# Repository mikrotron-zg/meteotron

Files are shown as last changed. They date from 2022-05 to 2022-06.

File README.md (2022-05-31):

# Meteotron

A simple weather station project based on [Adafruit](https://www.adafruit.com/) Feather ESP32-S2 and BME680. Basic version reads temperature, relative humidity and atmospheric pressure, connects to local Wi-Fi and sends data to [ThingsBoard](https://demo.thingsboard.io/) demo server. You can find current data from our test setup [here](https://bit.ly/3z5tDIx).

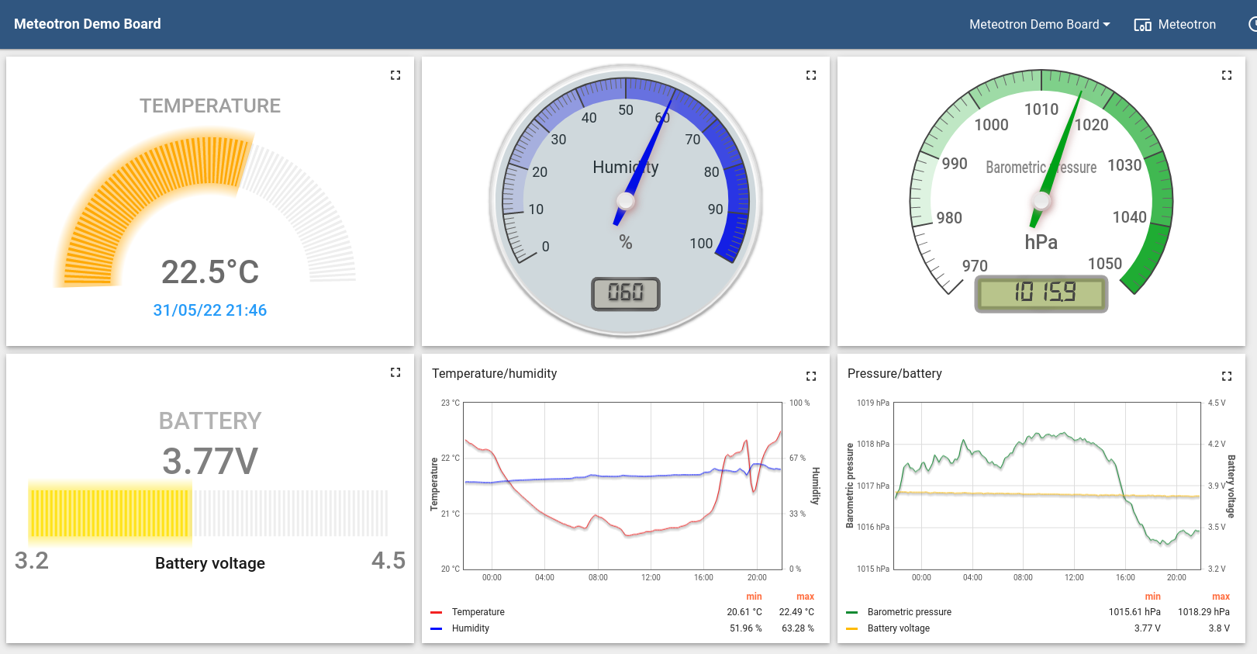
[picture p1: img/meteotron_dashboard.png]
meteotron dashboard


## Hardware

Hardware needed for this project:
* [Adafruit ESP32-S2 Feather](https://www.diykits.eu/products/wireless/p_12015) - great microcontroller board by [Adafruit](https://www.adafruit.com/), with some nice sleep/low power functions we're gonna need
* [BME680 Sensor Breakout](https://www.diykits.eu/products/sensors/p_11997) - reads temperature, relative humidity, atmospheric pressure and VOC (we won't be using this, so will probably switch to some other sensor once the chip shortage is over)
* [easyC cable - 10 cm](https://www.diykits.eu/products/connectorsandwires/p_11733) - eascyC or Stemma QT or Qwiic, it's all the same, easy way to connect I2C (IIC) devices
* [Li-ion battery 2100mAh 3.7V](https://www.diykits.eu/products/power/p_12004) - should be enough for what we need

Also, we can go solar by using:
* [Mini Solar Panel 5V 500mA](https://www.diykits.eu/products/power/p_10668) and
* [CN3065 Solar Lithium Charger Board](https://www.diykits.eu/products/power/p_11930) 

## Software

Project software is written in [VS Code](https://code.visualstudio.com/) with [PlatformIO](https://platformio.org/) plugin, but it can be compiled using [Arduino IDE](https://www.arduino.cc/en/software) (you might need to change a few things here and there, and manually download the libraries used in the project, but it should work). 

Before compiling, you must add your credentials (WiFi, ThingsBoard, etc), so please follow the instructions in _include/CredentialsTemplate.h_ file.

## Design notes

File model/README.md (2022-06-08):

3D model source files, you'll need [OpenSCAD](https://openscad.org/) to render and export STL files for 3D print.

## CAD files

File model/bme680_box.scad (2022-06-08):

/* Box for BME680 sensor module by e-radionica
 * by Mikrotron d.o.o. 2022
 * see the project root for license
 */

// should be in the same directory
include <mini_solar_common.scad>

// geometry
bme_length = 27.5;
bme_width = 16.5;
bme_pcb_height = 1.6;
bme_mthole_dia = 3.2;
bme_mthole_offset = 2.9;
wall_offset = 7;
box_wall = 2.4;
box_length = bme_length + 4*wall_offset;
box_width = bme_width + 2*wall_offset;
box_height = 16;
box_mh_offset = 4;
corner_radius = wall_offset + 2.8;
mh = mount_holes();
standoff_h = 3;

// entry point
bme680_box();

module bme680_box() {
    bme680_box_bottom();
    // translate([-box_wall, -box_wall, 0]) #bme680_box_top(); // used for construction
    translate([0, 2.25*box_width, box_height]) rotate([180, 0, 0]) bme680_box_top();
}

module bme680_box_top() {
    // top part of the box
    top_length = box_length + 2*box_wall;
    top_width = box_width + 2*box_wall;
    corner_height = box_height - 2*box_wall - standoff_h - 2*bme_pcb_height;
    difference() {
        union() {
            difference() {
                // body
                cube([top_length, top_width, box_height]);
                translate([box_wall, box_wall, -ex]) 
                    cube([box_length, box_width, box_height - box_wall + ex]);
                // vent grid
                translate([top_length/4, top_width/4, box_height - box_wall - ex]) {
                    for (i = [0 : top_length/20 : top_length/2]) {
                        translate([i, 0, 0]) cube([0.75, top_width/2, box_wall + 2*ex]);
                    }
                }
                // wire inlet
                translate([top_length - box_wall - ex, top_width/2 - inlet_width/2, box_wall]) 
                    cube([box_wall + 2*ex, inlet_width, inlet_height]);
            }
            // corners
            translate([box_wall, box_wall, box_height - box_wall - corner_height]) 
                cylinder_quarter(corner_radius, corner_height);
            translate([top_length - box_wall, top_width - box_wall, box_height - box_wall - corner_height]) 
                rotate(180) cylinder_quarter(corner_radius, corner_height);
        }
        // corner screw holes
        translate([box_wall + box_mh_offset, box_wall + box_mh_offset, box_height + ex]) 
            rotate([0, 180, 0]) m3_flathead_screw();
        translate([top_length - box_wall - box_mh_offset, top_width -box_wall - box_mh_offset, box_height + ex]) 
            rotate([0, 180, 0]) m3_flathead_screw();
    }
}

module bme680_box_bottom() {
    // bottom part of the box
    translate([wall_offset, wall_offset, box_wall + standoff_h]) %bme680();
    difference() {
        // body
        union() {
            cube([box_length, box_width, box_wall]);
            translate([0, 0, box_wall]) cylinder_quarter(corner_radius, standoff_h + 2*bme_pcb_height);
            translate([box_length, box_width, box_wall]) 
                rotate(180) cylinder_quarter(corner_radius, standoff_h + 2*bme_pcb_height);
            standoffs();
        }
        // holes for M2.5 screws
        translate([wall_offset, wall_offset, -ex]) {
            translate(mh[1]) cylinder(d = m25_dia, h = box_wall + standoff_h + 2*ex);
            translate(mh[3]) cylinder(d = m25_dia, h = box_wall + standoff_h + 2*ex);
        }
        // bottom nut traps
        translate([box_mh_offset, box_mh_offset, -ex]) nut_trap();
        translate([box_length - box_mh_offset, box_width - box_mh_offset, -ex]) nut_trap();
    }
}

module nut_trap() {
    // M3 nut trap
    cylinder(r = m3_nut_radius, h = 6, $fn = 6); 
    cylinder(d = m3_dia, h = box_wall + standoff_h + 2*bme_pcb_height + 2*ex);
}

module standoffs() {
    // BME680 standoffs
    translate([wall_offset, wall_offset, box_wall]) {
        for(mh = mount_holes()) translate(mh) cylinder(d1 = 8, d2 = 6, h = standoff_h);
        translate([0, 0, standoff_h]) {
            translate(mh[0]) cylinder(d = 2.75, h = 2*bme_pcb_height);
            translate(mh[2]) cylinder(d = 2.75, h = 2*bme_pcb_height);
        }
    }
}

//*************************** BME680 sensor module mockup *******************************

module bme680() {
    difference() {
        cube([bme_length, bme_width, bme_pcb_height]);
        for(mh = mount_holes()) translate(mh) bme_mthole();
    }
    translate([0, bme_width/2, bme_pcb_height]) rotate(-90) bme_connector();
    translate([bme_length, bme_width/2, bme_pcb_height]) rotate(90) bme_connector();
}

module bme_connector() {
    translate([-2.5, 0, 0]) cube([5, 4, 3.1]);
}

module bme_mthole() {
    cylinder(d = bme_mthole_dia, h = bme_pcb_height + 2*ex);
}

function mount_holes() =  [[bme_mthole_offset, bme_mthole_offset, -ex], 
                        [bme_length - bme_mthole_offset, bme_mthole_offset, -ex], 
                        [bme_length - bme_mthole_offset, bme_width - bme_mthole_offset, -ex], 
                        [bme_mthole_offset, bme_width - bme_mthole_offset, -ex]];

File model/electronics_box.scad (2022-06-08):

/* Electronics box (except for BME sensor,
 * we need it outside)
 * by Mikrotron d.o.o. 2022
 * see the project root for license
 */

// should be in the same directory
include <mini_solar_common.scad>;

// geometry
pcb_height = 1.6;
component_offset = 7.5;

// battery dimensions
bat_length = 62;
bat_width = 38;
bat_height = 9;

// charger dimensions
chrg_length = 40.5;
chrg_width = 20.5;
chrg_height = 8;

// feather dimensions
fthr_length = 50.8;
fthr_width = 23.0;
fthr_height = 7.2;
fthr_mnt_hole_dia = 2.54;
fthr_standoff_height = 5;

// box dimensions
box_length = bat_length + fthr_width + 3*component_offset;
box_width = chrg_width + bat_width + 3*component_offset;
box_height = fthr_height + 2*fthr_standoff_height + 5;
box_wall = 2.4;
bracket_distance = 95; // center to center!
corner_screw_offset = 6;

// entry point
mini_solar_box();

module mini_solar_box() {
    // comment out part if not needed
    color("Orange") box_top();
    translate([0, box_width*1.25, 0]) box_bottom();
}

module box_top() {
    // top part of the box
    difference() {
        translate([box_wall/2, box_wall/2, 0]) {
            rounded_rect(box_length - box_wall, box_width - box_wall, box_wall, box_wall/2);
        }
        // add corner screw holes
        translate([0, 0, box_wall + ex]) corner_screw_holes();
    }
    // add brackets
    translate([box_length/2 - bracket_distance/2, box_width/2, box_wall]) bracket();
    translate([box_length/2 + bracket_distance/2, box_width/2, box_wall]) bracket();
}

module corner_screw_holes(screw = true) {
    off = corner_screw_offset;
    translate([off, off, -ex]) m3_screw(screw);
    translate([box_length - off, off, -ex]) m3_screw(screw);
    translate([box_length - off, box_width - off, -ex]) m3_screw(screw);
    translate([off, box_width - off, -ex]) m3_screw(screw);
}

module corner() {
    radius = corner_screw_offset + 2.5;
    height = box_height - 2*box_wall;
    insert_height = height - 5;
    difference() {
        cylinder_quarter(r = radius, h = height);
        translate([corner_screw_offset - box_wall, corner_screw_offset - box_wall, insert_height]) 
            rotate(45) m3_screw(false);
        translate([radius/2 + 0.5, radius/2 + 0.5, insert_height]) 
            rotate(45) m3_screw(false);
    }
}

module corners() {
    translate([box_wall, box_wall, box_wall])  corner();
    translate([box_wall, box_width - box_wall, box_wall]) rotate(-90) corner();
    translate([box_length - box_wall, box_width - box_wall, box_wall]) rotate(180) corner();
    translate([box_length - box_wall, box_wall, box_wall]) rotate(90) corner();
}

module box_bottom() {
    // bottom part of the box
    difference() {
        rounded_rect(box_length, box_width, box_height, box_wall);
        translate([box_wall/2, box_wall/2, box_height - box_wall])
            rounded_rect(box_length - box_wall, box_width - box_wall, box_wall + 2*ex, box_wall/2);
        translate([box_wall, box_wall, box_wall])
            rounded_rect(box_length - 2*box_wall, box_width - 2*box_wall, box_height - box_wall, box_wall/2);
        // add power inlet
        translate([0.6*box_length, -ex, box_height/2])
            cube([inlet_width, box_wall + 2*ex, inlet_height]);
        // add-on mounts
        translate([bat_length + 2*component_offset, 4*component_offset, -ex]) bme680_mount(true);
    }
    // add corner screw mounts
    difference() {
        corners();
        translate([0, 0, box_height]) corner_screw_holes();
    }
    // components placement
    translate([0,0, box_wall]) {
        translate([component_offset + 1, chrg_width + 2*component_offset - 1, 0]) {
            battery_mount();
            %battery();    
        }
        translate([component_offset + bat_length/2 - chrg_length/2, component_offset, 0]) {
            translate([-box_wall/2, -box_wall/2, 0]) 
                charger_mount(chrg_length, chrg_width, 3);
            translate([0, 0, pcb_height]) %charger();
        }
        translate([bat_length + fthr_width + 2*component_offset, 2*component_offset, 0]) 
            rotate(90) {
                fthr_mount();
                translate([0, 0, fthr_standoff_height]) %feather();
            }
    }
    // add-on mounts
    translate([bat_length + 2*component_offset, 4*component_offset, box_wall]) bme680_mount();
}

//********************************* Component mounts *********************************************

module charger_mount(length, width, height) {
    // solar charger mount
    difference() {
        cube([length + box_wall, width + box_wall, height]);
        translate([box_wall/2, box_wall/2, height - pcb_height])
            cube([length, width, height + 2*ex]);
        translate([box_wall, box_wall, -ex])
            cube([length - box_wall, width - box_wall, height]);
        translate([-ex, width/2 - box_wall, 0])
            cube([length + 2*box_wall + 2*ex, 2*box_wall, height + ex]);
    }
    // hooks
    translate([length/4, 0, height]) hook();
    translate([3*length/4, 0, height]) hook();
    translate([length/4, width + box_wall, height]) rotate(180) hook();
    translate([3*length/4, width + box_wall, height]) rotate(180) hook();
}

module hook() {
    translate([-1, 0, 0]) cube([2, box_wall/2 + 0.4, box_wall/2]);
}

module fthr_mount() {
    // Adafruit Feather board mount
    translate([fthr_mnt_hole_dia, fthr_mnt_hole_dia, 0]) fthr_standoff();
    translate([fthr_mnt_hole_dia, fthr_width - fthr_mnt_hole_dia, 0]) fthr_standoff();
    ledge = 5;
    translate([fthr_length - ledge, -box_wall, 0]) difference() {
        cube([ledge + box_wall , fthr_width + 2*box_wall, fthr_standoff_height + 2*pcb_height]);
        translate([0, box_wall, fthr_standoff_height])
            cube([ledge, fthr_width, 1.5*pcb_height]);
        translate([0, box_wall + 1, fthr_standoff_height + 1.5*pcb_height])
            cube([ledge, fthr_width - 2, pcb_height]);
    }
}

module fthr_standoff() {
    difference() {
        screw_dia = m25_dia - 0.25; // m25_dia is for holes, we need this to be tight!
        cylinder(d1 = fthr_mnt_hole_dia + 6, d2 = fthr_mnt_hole_dia + 2, h = fthr_standoff_height);
        cylinder(d = screw_dia, h = fthr_standoff_height + ex);
    }
}

module battery_mount() {
    // lipo battery mount
    translate([bat_length/2, 0, 0]) rotate(90) battery_mount_clip(bat_length/2);
    translate([bat_length/2, bat_width, 0]) rotate(-90) battery_mount_clip(bat_length/2);
    translate([0, bat_width/2, 0]) battery_mount_clip();
    translate([bat_length, bat_width/2, 0]) rotate(180) battery_mount_clip();
}

module battery_mount_clip(clip_length = 3*box_wall) {
    clip_extension = 2;
    clip_xy = [[0, 0], [-clip_extension, clip_extension], 
                [-clip_extension, bat_height - clip_extension], [0, bat_height]];
    translate([-box_wall, clip_length/2, 0]) rotate([90, 0, 0]) {
        difference() {
            cube([box_wall + clip_extension, bat_height, clip_length]);
            translate([box_wall + clip_extension + ex, 0, -ex])
                linear_extrude(height = clip_length + 2*ex) polygon(clip_xy);
        }
        translate([box_wall, bat_height, 0]) {
            cylinder_quarter(r = box_wall, h = clip_length);
            rotate(90) cylinder_quarter(r = box_wall, h = clip_length);
        }
    }
}

//************************************* Add-on mounts *********************************************

module bme680_mount(nut_trap = false) {
    // BME680 box mount
    bme_length = 27.5;
    bme_width = 16.5;
    bme_mthole_offset = 2.9;
    translate([bme_width - bme_mthole_offset, bme_mthole_offset, 0]) bme680_nut_trap(nut_trap);
    translate([bme_mthole_offset, bme_length - bme_mthole_offset, 0]) bme680_nut_trap(nut_trap);
}

module bme680_nut_trap(full = false) {
    if (full) {
        cylinder(d = m25_dia, h = 2);
        translate([0, 0, 2]) cylinder(r = m25_nut_radius, h = 2.5 + ex, $fn = 6);
    } else {
        difference() {
            cylinder(d = 7.5, h = 2.5);
            cylinder(r = m25_nut_radius, h = 2.5 + ex, $fn = 6);
        }
    }
}

//************************************* Components mock up ****************************************

module battery() {
    cube([bat_length, bat_width, bat_height]);
}

module charger() {
    cube([chrg_length, chrg_width, pcb_height]);
}

module feather() {
    cube([fthr_length, fthr_width, pcb_height]);
}

//**************************************** Common modules ******************************************

module m3_screw(screw = true) {
    if (screw) {
        rotate([180, 0, 0]) m3_flathead_screw();
    } else {
        // M3 nut trap 
        cylinder(r = m3_nut_radius, h = 2.5, $fn = 6);
    }
}

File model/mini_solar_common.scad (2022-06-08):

/* Common module used by other *.scad files
 * by Mikrotron d.o.o. 2022
 * see the project root for license
 */

// Dimensions of screws used in this project
m25_dia = 2.75; // used for holes, so we need them to be bigger
m25_nut_radius = nut2radius(5);
m3_dia = 3.4; // used for holes, so we need them to be bigger
m3_screw_head_h = 2;
m3_nut_radius = nut2radius(5.5);
m5_dia = 5.3; // used for holes, so we need them to be bigger
m5_nut_radius = nut2radius(8);

// Bracket dimensions
bracket_width = 5;
bracket_length = 15;

// Wire inlet dimensions
inlet_width = 8;
inlet_height = 5;

// Other common variables
$fn = 200; // needed for smoother curved surfaces
ex = 0.001; // needed for cleaner preview

//********************* Common parts ************************************************

module rounded_rect(x, y, z, radius = 1) {
    // Draws a rounded rectangle
    translate([radius,radius,0]) //move origin to outer limits
	linear_extrude(height=z)
		minkowski() {
			square([x-2*radius,y-2*radius]); //keep outer dimensions given by x and y
			circle(r = radius, $fn=200);
		}
}

module cylinder_quarter(r, h){
    // Draws quarter of a cylinder
    difference(){
        cylinder(r=r, h=h);
        translate ([-r-ex, -r-ex, -ex]) cube([2*r + 2*ex, r + ex, h + 2*ex]);
        translate ([-r-ex, -ex, -ex]) cube([r + ex, r + ex, h + 2*ex]);
    }
}

module m3_flathead_screw() {
    // Draws flathead M3x10 screw
    cylinder(d1 = 5.8, d2 = m3_dia, h = m3_screw_head_h);
    translate([0, 0, m3_screw_head_h]) cylinder(d = m3_dia, h = 10 - m3_screw_head_h);
}

module bracket(width = bracket_width, length = bracket_length) {
    // Draws mounting bracket
    $fn = 200;
    difference() {
        union() {
            translate([-width/2, 0, length/2]) rotate([0, 90, 0])
                cylinder(d = length, h = width);
            translate([-width/2, -length/2, 0])
                cube([width, length, length/2]);
        }
        translate([-width/2-ex, 0, length/2]) rotate([0, 90, 0]) 
            cylinder(d = m5_dia, h = width + 2*ex);
    }
    // Add reinforcements
    translate([-width/2, length/2, 0]) reinforcement_radius(width);
    translate([width/2, -length/2, 0]) rotate(180) reinforcement_radius(width);
}

module reinforcement_radius(width) {
    // Needed for mounting bracket
    translate([0, width, width]) rotate([0, 90, 0]) difference() {
        translate([0, - width, 0]) cube([width, width, width]);
        translate([0, 0, -ex]) cylinder(d = width*2, h = width + 2*ex);
    }
}

//********************* Small parts ************************************************

module inlet_plug(small = true) {
    // Should be printed in TPU
    rim = 1;
    wall = 2.75;
    gap = 0.5;
    difference() {
        union() {
            cube([inlet_width + rim, inlet_height + rim, rim]);
            translate([rim/2, rim/2, rim]) cube([inlet_width, inlet_height, wall]);
        }
        translate([inlet_width/2 - gap/2 + rim/2, -ex, -ex]) 
            cube([gap, inlet_height/2, wall + 2*rim + 2*ex]);
        if (small) {
        translate([inlet_width/4 + rim/2, inlet_height/3 + rim/2, -ex]) 
            cube([inlet_width/2, inlet_height/3, wall + 2*rim + 2*ex]);
        } else {
        translate([inlet_width/6 + rim/2, inlet_height/4 + rim/2, -ex]) 
            cube([2*inlet_width/3, inlet_height/2, wall + 2*rim + 2*ex]);
        }
    }
}

// Uncomment to generate inlet plug
//inlet_plug();  // small opening
//inlet_plug(false);  // big opening

module distancer(wall = 2.4, height = 1) {
    difference() {
        cylinder(d = m25_dia + 2*wall, h = height);
        translate([0, 0, -ex]) cylinder(d = m25_dia, h = height + 2*ex);
    }
}

// Uncomment to generate
//distancer();

//********************* Functions ************************************************

// Calculates nut radius from metric nut size (wrench size)
function nut2radius(m) = m/2/cos(180/6);

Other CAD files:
model/mini_solar_panel_frame.scad
model/mini_solar_panel_holder.scad
model/pole_mount.scad

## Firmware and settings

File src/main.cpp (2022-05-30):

//#define DEBUG_MODE // please read the instructions in include/Debug.h file

#include <Arduino.h>
#include <WiFi.h>
#include <SPI.h>
#include <Adafruit_LC709203F.h>
#include "BME680-SOLDERED.h"
#include "ThingsBoard.h"
#include "Configuration.h" // please read the instructions in include/Configuration.h file
#include "Credentials.h" // please read the instructions in include/CredentialsTemplate.h file
#include "Debug.h"

bool connectToWiFi() {
  // Connect to WiFi network
  DEBUG("Connecting to WiFi network: ");DEBUGLN(WIFI_SSID);
  WiFi.mode(WIFI_STA);
  if (WiFi.status() != WL_CONNECTED) {
    WiFi.begin(WIFI_SSID, WIFI_PASSWORD);
  }
  if (WiFi.waitForConnectResult() == WL_CONNECTED) {
    DEBUGLN("WiFi connected!");
    return true;
  } 
  DEBUGLN("WiFi not connected, check your credentials");
  return false;
}

void powerOn() {
// turn on the I2C power by setting pin to LOW
  pinMode(PIN_I2C_POWER, OUTPUT);
  digitalWrite(PIN_I2C_POWER, LOW);
}

void checkBattery() {
  // Get battery readings
  Adafruit_LC709203F lc;
  if (!lc.begin()) {
    DEBUGLN("Could not find Adafruit LC709203F or battery not plugged in!");
    return;
  }
  delay(DELAY_STANDARD);
  sensorData.batteryVoltage = lc.cellVoltage();
  delay(DELAY_STANDARD);
  sensorData.batteryPercentage = lc.cellPercent();
  DEBUG("Batt Voltage: "); DEBUGLN(sensorData.batteryVoltage);
  DEBUG("Batt Percent: "); DEBUGLN(sensorData.batteryPercentage);
}

void readBME() {
  // Read and save BME680 data
  BME680 bme680;
  bme680.begin();
  bme680.setGas(0, 0); // turn the gas sensor heater off
  delay(DELAY_LONG);
  sensorData.temperature = bme680.readTemperature();
  delay(DELAY_LONG);
  sensorData.humidity = bme680.readHumidity();
  delay(DELAY_LONG);
  sensorData.pressure = bme680.readPressure() + PA_PER_METER*ALTITUDE;
  DEBUG("Temperature: "); DEBUGLN(sensorData.temperature);
  DEBUG("Humidity: "); DEBUGLN(sensorData.humidity);
  DEBUG("Atm. pressure: "); DEBUGLN(sensorData.pressure);
}

bool readSensors(const byte max_retry) {
  for (byte i = 0; i < max_retry; i++) {
    powerOn(); // power on the I2C bus
    delay(DELAY_LONG);
    checkBattery();
    delay(DELAY_LONG);
    readBME();
    delay(DELAY_LONG);
    // if BME680 reads anything but defaults: RH: 100% & temp 34.17
    if (sensorData.humidity < 99.9 && 
        (sensorData.temperature < 34.16 || sensorData.temperature > 34.18)) {
          DEBUGLN("Sensor data successfully read.");
          return true;
        }
  }
  // failed to read data
  DEBUGLN("Sensor read not successful!");
  return false;
}

void uploadData() {
  // Initialize ThingsBoard client
  WiFiClient espClient;
  // Initialize ThingsBoard instance
  ThingsBoardSized<128> tb(espClient); // we need more than default 64 bytes to send data
  if (!tb.connect(THINGSBOARD_SERVER, TOKEN)) {
      DEBUG("Failed to connect to "); DEBUGLN(THINGSBOARD_SERVER);
      return;
  }
  DEBUGLN("Sending data to server");
  const int data_items = 4;
  Telemetry data[data_items] = {
    {"temperature", sensorData.temperature},
    {"humidity", sensorData.humidity},
    {"pressure", sensorData.pressure},
    {"battery", sensorData.batteryVoltage}
  };
  tb.sendTelemetry(data, data_items);
  delay(1000);
  tb.disconnect();
}

void gotoSleep() {
  // Go to deep sleep
  DEBUGLN("Going to sleep for 10 minutes");
  WiFi.disconnect();
  delay(1000);
  WiFi.mode(WIFI_OFF);
  pinMode(PIN_I2C_POWER, OUTPUT);
  digitalWrite(PIN_I2C_POWER, HIGH);
  delay(1000);
  esp_sleep_enable_timer_wakeup(600000000L); // 10 minutes in microseconds
  esp_deep_sleep_start();
}

void setup() {
  // Program entry point
  #ifdef DEBUG_MODE // if in debug mode, start the serial connection
    Serial.begin(115200); // preffered baud rate for ESP32's
    while(!Serial); // wait for serial connection to be ready
    delay(5000); // give us time to open serial monitor if closed
  #endif
  DEBUGLN("Debug mode on"); // let us know you're ready
  delay(DELAY_SHORT);
  if (!connectToWiFi()) gotoSleep();
  if (readSensors(3)) {
    // upload data only upon successful sensor read
    uploadData();
  }
  delay(DELAY_LONG);
  gotoSleep();
}

void loop() {
  // nothing to do here
}

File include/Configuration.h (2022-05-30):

/*******************************************************************
 * This files contains global constants and variables used in project. 
 * Review and change (if needed) values where comment starts with CHANGEME
 *******************************************************************/
#ifndef CONFIGURATION_H
    #define CONFIGURATION_H

    // Constants
    #define PIN_I2C_POWER 7 // needed for I2C power management
    #define PA_PER_METER 0.113 // approx. pressure change in hPa per meter of altitude (up to 1000m)
    #define ALTITUDE 120.0 // CHANGEME meteo station altitude above sea level (in meters)
    // Delays (in miliseconds) needed in program
    #define DELAY_LONG 3000 // if you're getting incorrect readings from sensor, try longer delay
    #define DELAY_STANDARD 250
    #define DELAY_SHORT 25

    // Variables
    typedef struct SensorData { // we'll group all the data we collect in a single struct
        float temperature = 0.0;
        float humidity = 0.0;
        float pressure = 0.0;
        float batteryVoltage = 0.0;
        float batteryPercentage = 0.0;
    } SensorData;
    SensorData sensorData;
#endif

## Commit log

2022-05-22 Implemented battery check
2022-05-23 Added Configuration.h
    [Configuration.h]
2022-05-25 Implemented data upload to ThingsBoard demo server
    [Configuration.h]
2022-05-30 Sensor read function with error detection and retry
    [Configuration.h]
2022-06-08 Added 3D model OpenSCAD source files
    [bme680_box.scad, electronics_box.scad, mini_solar_common.scad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]
